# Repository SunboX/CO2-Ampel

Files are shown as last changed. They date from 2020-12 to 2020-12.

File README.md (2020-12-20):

# CO2-Ampel

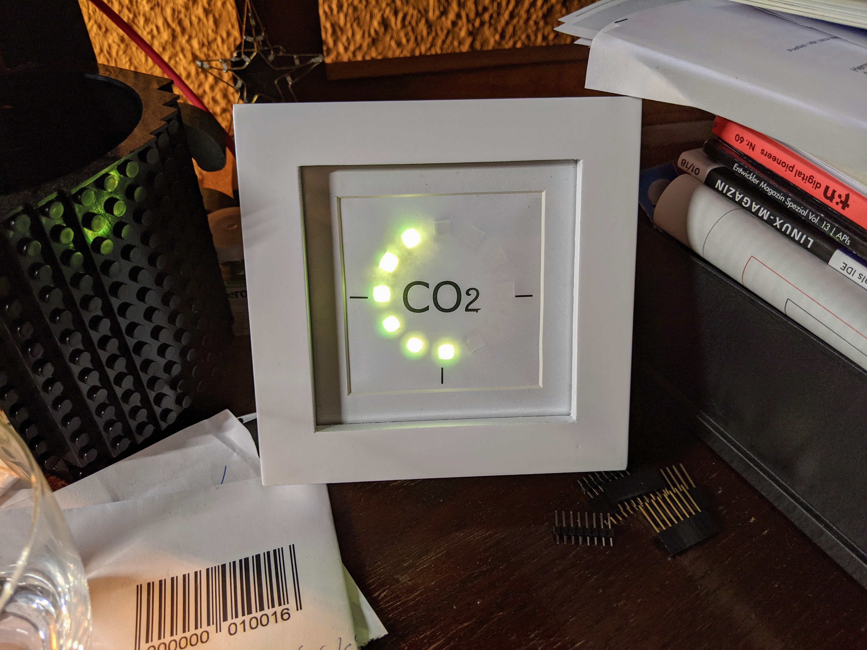
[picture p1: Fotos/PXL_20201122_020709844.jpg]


Angeregt durch den "CO2-Warner für die Schule" Artikel im MAKE: Magazin 5/2020 {1] habe ich einen CO2 Warner für mein Home Office gebaut.

Zu viel CO2 in der Raumluft vermehrt nicht nur Ansteckungen, sondern führt auch zu starken Kopfschmerzen, Leistungsabfall, Konzentrationsschwäche und zu erhöhter Atemfrequenz.

Je nach CO2 Anteil in der Luft nimmt die LED Anzeige des Sensor zu. Dabei Ändert sich die Farbe aller LEDs von Grün ("gute" Luft), über Orange bis zu Rot. Steigt der Wert über 2000 ppm, fängt die Anzeige zusätzlich an zu blinken. Dann sollte dringend gelüftet werden.

## BOM

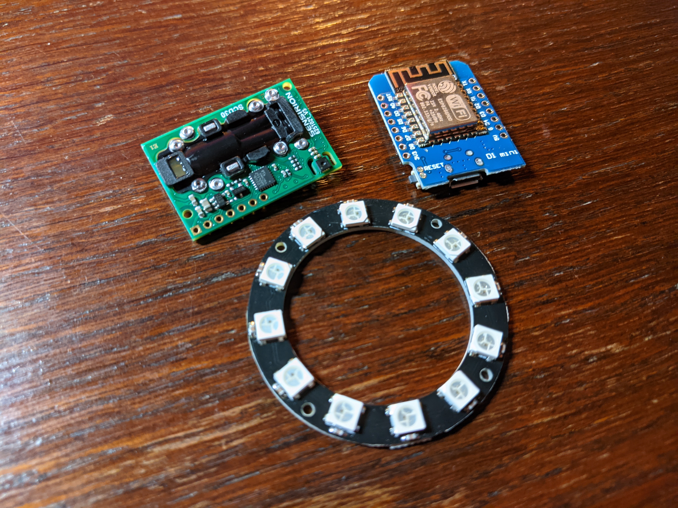
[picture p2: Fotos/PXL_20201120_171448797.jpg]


- Sensirion SCD30 (https://a.aliexpress.com/_mq1Fatr)
- Wemos D1 Mini (https://www.amazon.de/dp/B08BTYHJM1/ref=cm_sw_r_cp_apa_fabc_Veo3Fb7N104TA)
- 37mm RGB LED Ring (https://www.amazon.de/dp/B07PFFJ8TF/ref=cm_sw_r_cp_apa_fabc_Nfo3FbM20TVWF)
- Kupferschaltdraht 0,5mm ca. 20cm
- 10x10cm Bilderrahmen aus dem dm-Drogerie-Markt (https://www.dm.at/paradies-quadratischer-diy-bilderrahmen-sort-p4058172406720.html)
- 1 Blatt DIN A4 Papier mit 70g
- 2 Blatt DIN A4 Papier mit 110g
- 1 Micro USB Kabel (https://de.aliexpress.com/item/32858516897.html)

## Zusammenbau Elektronik

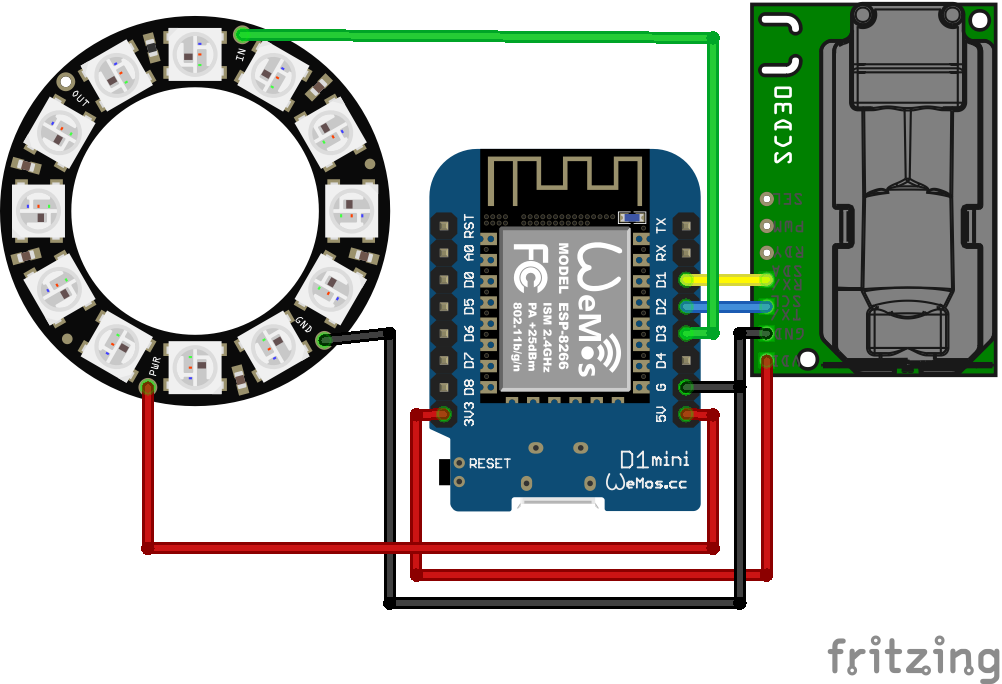
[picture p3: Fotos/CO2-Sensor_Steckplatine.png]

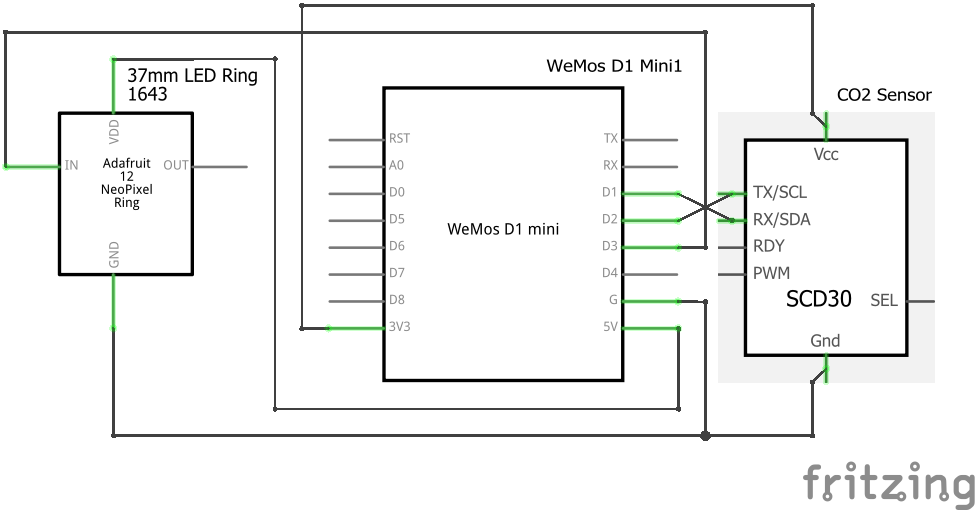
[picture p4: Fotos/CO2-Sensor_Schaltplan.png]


Die Anschlüsse anhand der Zeichnungen oben mit dünnem Draht (Kupferschaltdraht 0,5mm) verbinden. Je nachdem, ob ihr Tx/Rx und D1/D2 richtig oder "falsch" verbunden hab, müsst ihr `Wire.begin(D2, D1);` im Code noch anpassen. (D1 und D2 vertauschen!)



## Software Installation

In der Arduino IDE den ESP8266 - Wemos D1 Mini / R1 auswählen. falls noch nicht vorhanden, vorher die ESP8266 Boards hinzufügen.

Danach den Sketch aus dem `/Arduino` Ordner öffnen und auf den Wemos laden.

## Anzeige / Passepartout

Aus dem `/Schnittmuster` Ordner das Dokument "Anzeige" auf das 70g papier und das Dokument "Passepartout" auf das 110g papier drucken.

Eines der beiden Passepartouts mit einem Cutter-Messer und Stahllineal ausschneiden. Das zweite Passepartout dient als "Trennschicht" zwischen LED Ring und Wemos/CO2 Sensor.

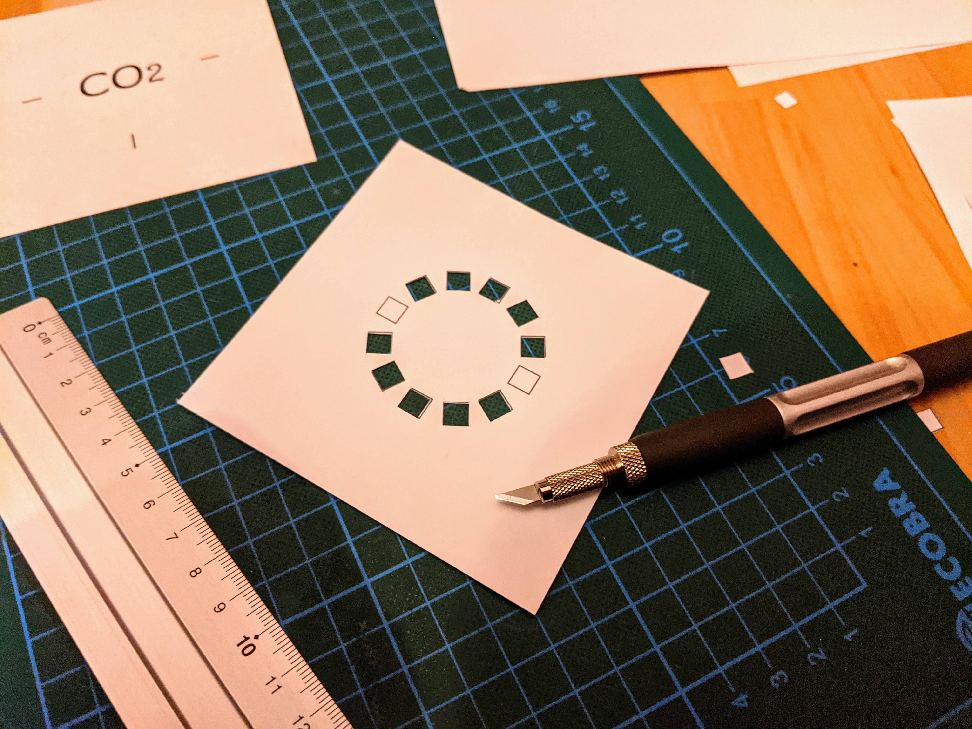
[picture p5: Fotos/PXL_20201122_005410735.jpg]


## Zusammenbau

Den Bilderrahmen auspacken und die Ecken des Rückteils am besten mit einem Cutter-messer und Stahllineal abschneiden, damit genügend Zirkulation entsteht.

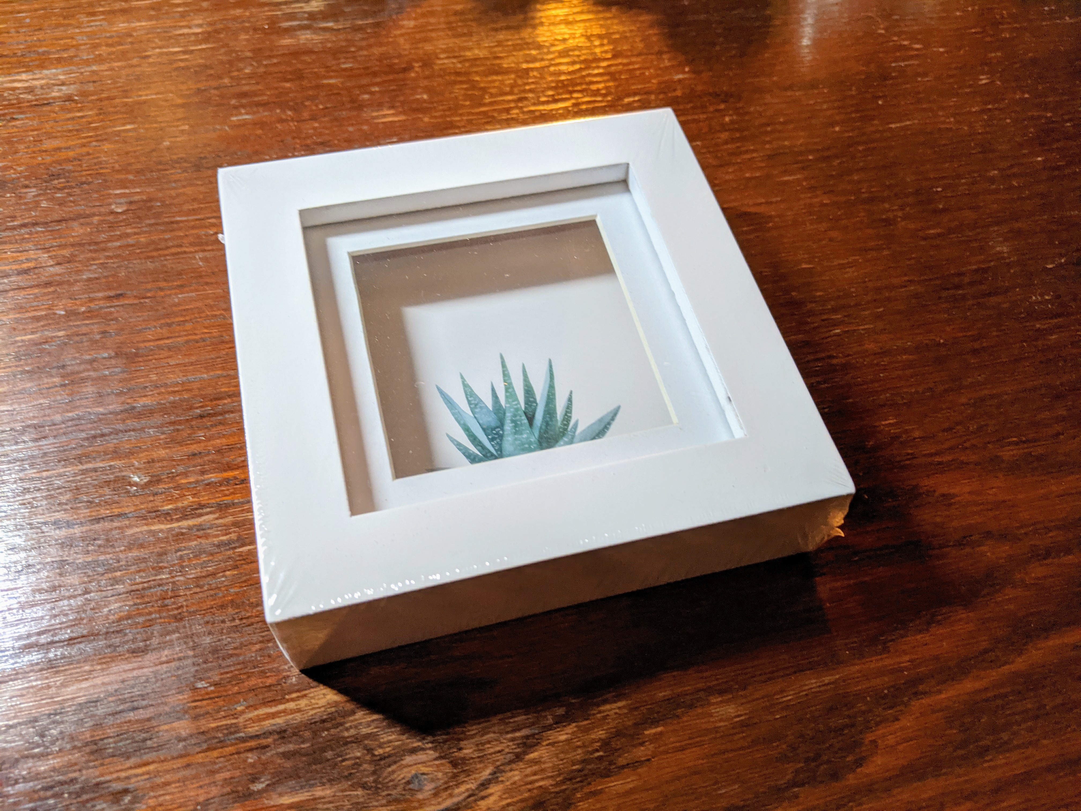
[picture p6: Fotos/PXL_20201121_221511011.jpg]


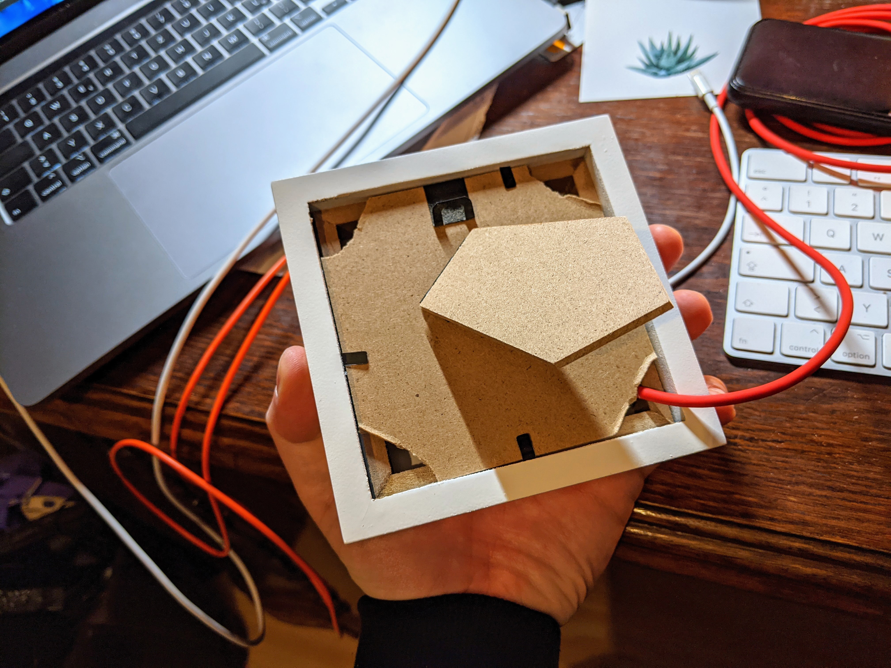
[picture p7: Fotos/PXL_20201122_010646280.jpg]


Nun die "Anzeige" auf das Glas legen. Das ausgeschnittene Passepartout über die einzelnen LEDs "stülpen". Das zweite Passepartout mit einem Ausschnitt für die Kabel des LED Ring versehen und zwischen Ring und Wemos/Sensor stecken. Gegebenfalls mit etwas Tesa fixieren. Das USB Kabel einstecken und alles zusammen in den Bilderrahmen, auf die Anzeige legen. Als nächstes den inneren Rahmen wieder einfügen. Nun den Decken mit den fehlenden Ecken wieder montieren und den Bilderrahmen "verriegeln". 

et voilà

[1] Zum Artikel aus dem MAKE: Magazin: https://www.heise.de/select/make/2020/5/2022015381334973804

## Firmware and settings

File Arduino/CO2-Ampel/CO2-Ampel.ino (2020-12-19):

#include <paulvha_SCD30.h>
#include <Wire.h>
#include <ESP8266WiFi.h>
#include <FastLED.h>

#define SCD30_ADDRESS 0x61

#define D1 5
#define D2 4
#define D3 0

int CO2 = 0 ;

// Anzahl der "NeoPixel"
#define NUM_PIXELS 12

#define START_LED 10

// Mit welchem GPIO ist der LED-Strip verbunden?
#define PIXEL_PIN 0

#define COLOR_ORDER RGB

// Bereich 0-64
#define BRIGHTNESS 50

// Definition des Pixelarray
CRGB pixels[NUM_PIXELS];

// Start Position des Cycling-Effekt
int pixelAddress = 0;

SCD30 airSensorSCD30; // Objekt SDC30 Umweltsensor

void setup() { // Einmalige Initialisierung
  Serial.begin(115200);
  Serial.println("Starting...");

  WiFi.forceSleepBegin(); // Wifi off

  Wire.begin(D2, D1); // ---- Initialisiere den I2C-Bus

  //Wire.setClock(100000L);            // 100 kHz SCD30
  //Wire.setClockStretchLimit(200000L);// CO2-SCD30

  if (Wire.status() != I2C_OK) {
    Serial.println("Something wrong with I2C");
  }

  if (airSensorSCD30.begin(Wire, false) == false) {
    Serial.println("The SCD30 did not respond. Please check wiring.");

    delay(300);

    while (1) {
      yield();
      delay(1);
    }
  }

  airSensorSCD30.setAutoSelfCalibration(false); // Sensirion no auto calibration

  airSensorSCD30.setMeasurementInterval(2);     // CO2-Messung alle 5 s

  // Den LED-Streifen initialisieren und die Helligkeit einstellen
  FastLED.addLeds<NEOPIXEL, PIXEL_PIN>(pixels, NUM_PIXELS); // Init der Fastled-Bibliothek
  FastLED.setBrightness(BRIGHTNESS);
}

void loop() { // Kontinuierliche Wiederholung
  CO2 = airSensorSCD30.getCO2() ;
  Serial.print("CO2:" + String(String(CO2)));
  Serial.println();

  if (CO2 < 600) {
    show(1, 0x00FF00);
  } else if (CO2 < 700) {
    show(2, 0x2EFF00);
  } else if (CO2 < 800) {
    show(3, 0x5DFF00);
  } else if (CO2 < 900) {
    show(4, 0x8BFF00);
  } else if (CO2 < 1000) {
    show(5, 0xB9FF00);
  } else if (CO2 < 1100) {
    show(6, 0xE8FF00);
  } else if (CO2 < 1200) {
    show(7, 0xFFE800);
  } else if (CO2 < 1300) {
    show(8, 0xFFB900);
  } else if (CO2 < 1400) {
    show(9, 0xFF8B00);
  } else if (CO2 < 1500) {
    show(10, 0xFF5D00);
  } else if (CO2 < 1600) {
    show(11, 0xFF2E00);
  } else if (CO2 < 2000) {
    show(12, 0xFF0000);
  }

  // Alert
  if (CO2 >= 2000) {
    show(0, 0x000000);
    delay(1000);
    show(12, 0xFF0000);
    delay(1000);
    show(0, 0x000000);
    delay(1000);
    show(12, 0xFF0000);
    delay(1000);
    show(0, 0x000000);
    delay(1000);
    show(12, 0xFF0000);
    delay(1000);
    show(0, 0x000000);
    delay(1000);
    show(12, 0xFF0000);
    delay(1000);
  }
  else {
    delay(2000);
  }
}

void show(int numPixels, CRGB color) {

  for (int i = 0; i < NUM_PIXELS; i++)
  {
    pixels[i] = CRGB::Black; // Schaltet alle LEDs aus
  }

  int curLED = START_LED;

  while (numPixels--) {
    pixels[curLED++] = color;
    if (curLED == NUM_PIXELS) {
      curLED = 0;
    }
  }

  FastLED.show();
}

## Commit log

2020-12-15 better structur, added cut marks
2020-12-17 not all sensors are working with this setting
2020-12-19 better sensor support & better cut files
2020-12-19 added Fritzing file
    [CO2-Sensor.fzz]
